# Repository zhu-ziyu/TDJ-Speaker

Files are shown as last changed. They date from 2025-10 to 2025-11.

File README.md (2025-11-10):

# Bluetooth Speaker — Design & Build Report

**Course:** TDJ4M1  
**Teacher:** Mr. Watson  
**Students:** Oscar Chen, Sam Zhu  
**Date:** Oct 1, 2025

---

## Table of Contents

- [Overview](#overview)
- [Goals & Constraints](#goals--constraints)
- [Design Criteria](#design-criteria)
- [Investigation & Research](#investigation--research)
- [Concepts & Sketches](#concepts--sketches)
- [CAD, Printing & Assembly](#cad-printing--assembly)
- [Electronics](#electronics)
- [Manufacturing Notes](#manufacturing-notes)
- [Cost & Production](#cost--production)
- [Timeline](#timeline)
- [Evaluation](#evaluation)
- [Critical Reflection](#critical-reflection)
- [Repository Structure](#repository-structure)
- [Build & Print Instructions](#build--print-instructions)
- [Future Work](#future-work)
- [License](#license)

---

## Overview

This project delivers a **compact, portable Bluetooth sound system** designed and fabricated in **Fusion 360** and produced via **3D printing**.  
The enclosure houses:

- 2 main speakers + 2 auxiliary speakers + 1 subwoofer  
- 2 control boards  
- Accessible ports, buttons, and battery compartment  
- **Magnetic fluid (“ferrofluid”) display** that “dances” to music via a controllable electromagnet  
- **Flip-top back** and **magnetic front/back coupling** for easy maintenance  
- Internal **LED illumination** that reveals **thinned light channels** in the surface design  

> The design balances **functionality, safety, and aesthetics**, ensuring stable internal structure and a futuristic, creature-like appearance.

---

## Goals & Constraints

- **Functionality:** Secure internal components, accessible ports, vibration-resistant.  
- **Printability:** Modular, fits standard FDM printers.  
- **Serviceability:** Flip-top lid, magnetic connection.  
- **Aesthetics:** Light-transmitting surface patterns, mascot features.  
- **Safety:** Rounded edges, locally compatible electronics.

---

## Design Criteria

| Category  | Specification |
|---|---|
| **Size** | Must fit within printer build volume; stable on table |
| **Function** | All buttons, speakers, and ports functional; components secured |
| **Materials** | 3D-printed plastic, strong but safe edges |
| **Aesthetics** | Clean, futuristic look with LED patterns |

---

## Investigation & Research

- **Pros:** Stable base designs, portability, good sound projection.  
- **Cons:** Spherical forms are unstable, some lack volume control.  

Key learnings:
- Front controls improve usability.  
- Symmetrical shapes enhance sound balance.  
- Transparent/lighted elements improve aesthetics.

---

## Concepts & Sketches

### Oscar’s Concept
- Cat-face front with ferrofluid as “face”  
- Multi-feet for stability and personality  
- 5-speaker array for richer audio  
- Magnetic front/back and flip-top design  
- Thinned wall patterns illuminated by LEDs  

### Sam’s Concept
- Stable internal structures for all components  
- Button extension mechanisms  
- Custom holders for speakers without screw holes  

Both ideas were combined into the final design: a cute yet futuristic speaker with advanced lighting and ferrofluid display.

---

## CAD, Printing & Assembly

> All files are available at:  
> [GitHub Repository](https://github.com/zhu-ziyu/TDJ-Speaker)

### Key Dates
- **Oct 18–19:** Initial CAD of enclosure; first test prints.  
- **Oct 20–23:** Flip-top, magnet connections, and button extensions.  
- **Oct 24:** Refined back panel and circuit board holes.  
- **Oct 27–29:** Added LED patterns and mascot; replaced electromagnet with local-safe version.  
- **Oct 31–Nov 4:** Final printing, soldering, and full assembly.

---

## Electronics

- **Main Components:** Two circuit boards, electromagnet, five speakers, LED lights.  
- **Feature:** Ferrofluid bottle reacts to music via controlled electromagnet.  
- **Fix:** Replaced unsafe imported electromagnet with Canada-compatible version.

---

## Manufacturing Notes

- **Material:** ABS (or PETG as alternative)  
- **Tolerances:** Precision snap-fits, magnet seats  
- **Orientation:** Printed to reduce visible supports  
- **Serviceability:** Flip-top hinge and magnetic coupling tested

---

## Cost & Production

| Item | Value |
|---|---|
| **Material Cost (per unit)** | $62 CAD (tax included) |
| **Print Time** | 11 hours |
| **Suggested Retail** | $128 CAD |

---

## Timeline

| Date | Activity |
|---|---|
| Oct 1–10 | Approval, drafts, PCB modeling |
| Oct 16–23 | Final draft selection, modeling, magnet design |
| Oct 24–31 | LED patterning, new electromagnet, mascot |
| Nov 3–4 | Final assembly, soldering, testing |

---

## Evaluation

### Oscar
- **Strengths:** Advanced modeling, ferrofluid feature, and LED design.  
- **Successes:** Perfect component fitting, magnet system, user-friendly assembly.  
- **Improvements:** Add programmable RGB LEDs.  
- **Learned:** Check voltage compatibility before sourcing components.

### Sam
- **Strengths:** Assembly precision, soldering, stable mounts, troubleshooting.  
- **Successes:** Solved unstable speaker issue with custom holder.  
- **Improvements:** Explore stronger, more aesthetic materials.  
- **Learned:** Early verification of parts saves time.

---

## Critical Reflection

### Oscar
- **What went well:** Implemented complex modeling and safe electronics.  
- **What to improve:** Add RGB LED system reactive to music.  
- **Learned:** Importance of regional voltage verification.  
- **If starting over:** Prototype LED and verify all components early.

### Sam
- **What went well:** Produced stable, functioning assembly.  
- **What to improve:** Research material upgrades.  
- **Learned:** Value of creating testing protocols early.  
- **If starting over:** More testing time for final soldering.

---

## Repository Structure

.
├── README.md
├── cad/
│ ├── fusion360/
│ └── assemblies/
├── stl/
│ ├── front_panel/
│ ├── back_panel_flip_top/
│ ├── magnet_couplers/
│ ├── button_extensions/
│ ├── speaker_holders/
│ └── feet_and_decors/
├── electronics/
│ ├── schematic/
│ └── bom.csv
├── docs/
│ ├── images/
│ ├── daily-tracker.md
│ └── evaluation.md
└── licenses/
└── LICENSE

---

## Build & Print Instructions

1. **Print**
   - Material: ABS/PETG  
   - Layer height: 0.2 mm  
   - Infill: 25%  
   - 3–4 perimeters  
   - Iron top surfaces if needed  

2. **Assemble**
   - Press magnets into couplers  
   - Mount speakers, electromagnet, ferrofluid bottle  
   - Connect wiring and solder  
   - Attach LEDs and test illumination  
   - Assemble front/back using magnetic connection  

3. **Test**
   - Audio balance  
   - Button functionality  
   - LED brightness and uniformity  

---

## Future Work

- RGB addressable LEDs  
- Stronger materials (carbon-fiber-filled filament)  
- Better acoustic dampening  
- Improved electromagnet power efficiency  
- Instruction manual and print guide

---

## License

Licensed under MIT License.  
© 2025 Oscar Chen & Sam Zhu — *Making sound you can see.* 🎧

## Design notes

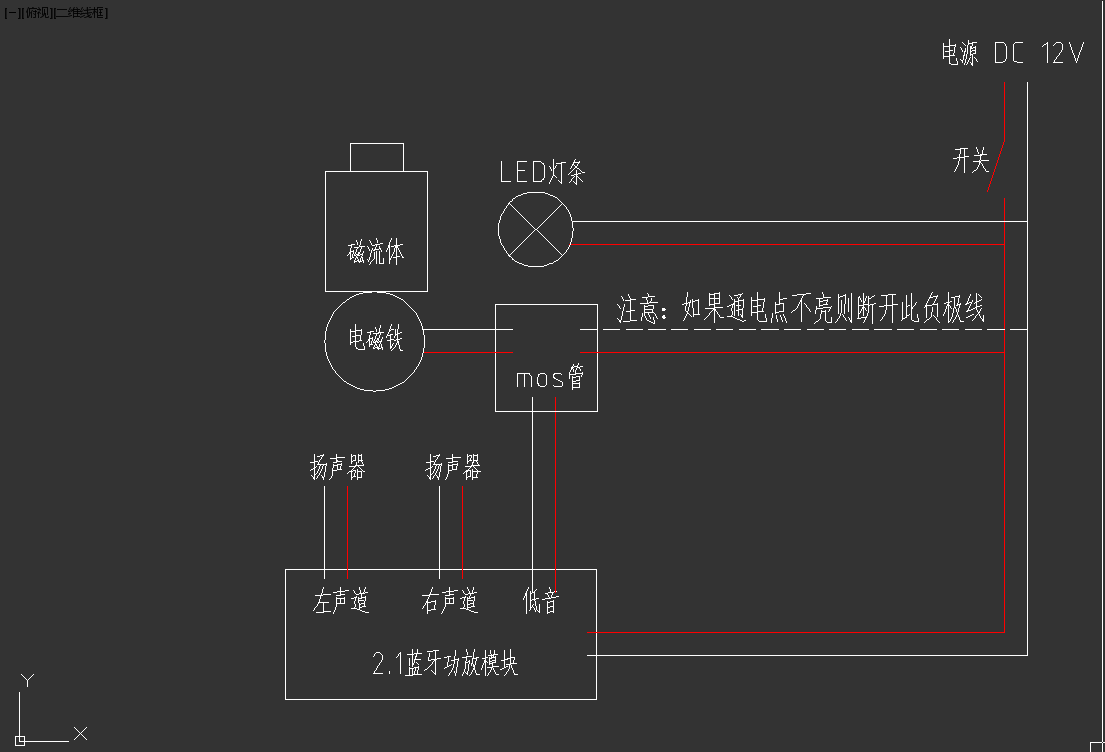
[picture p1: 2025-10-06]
参考文献/电路连接(来自毕导TSU的立创开源).png

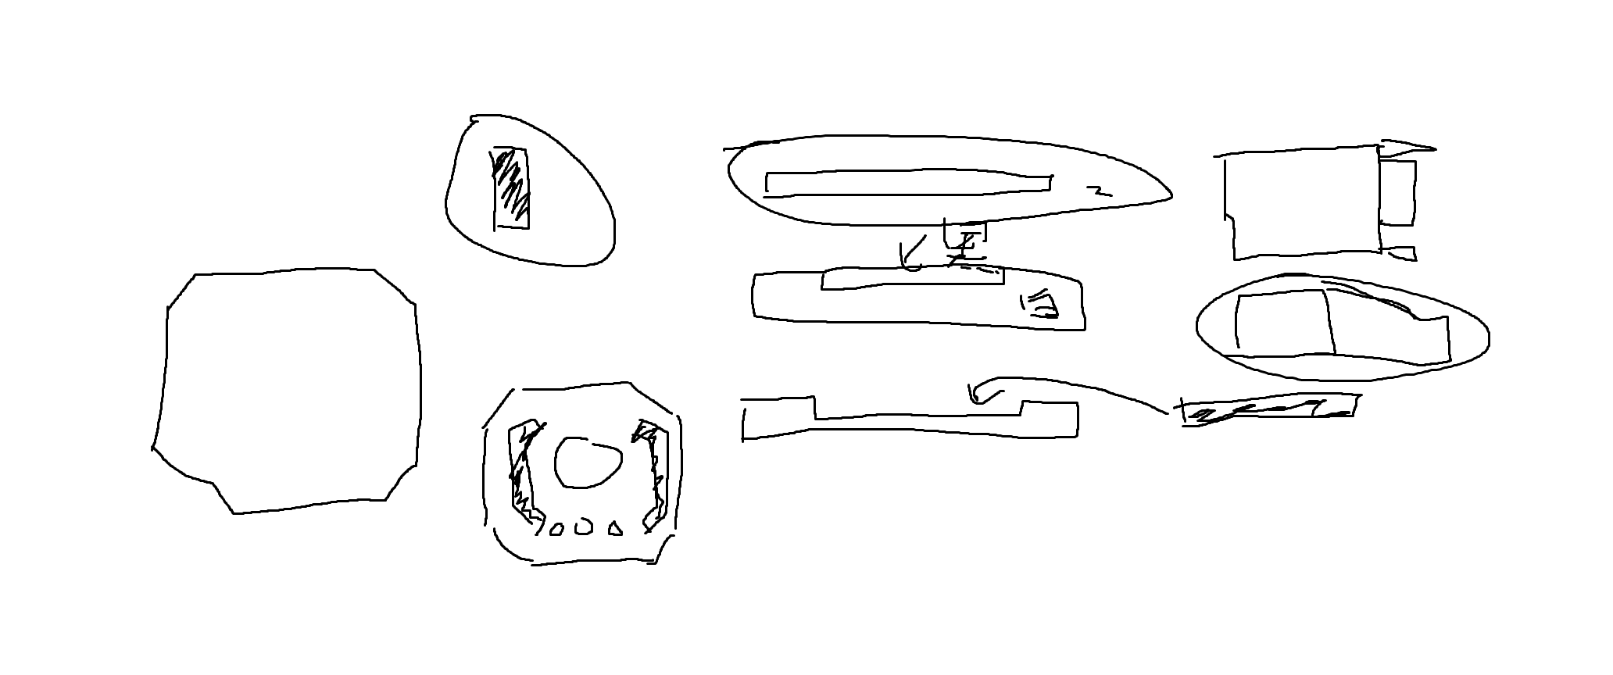
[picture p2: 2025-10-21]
参考文献/无标题.png

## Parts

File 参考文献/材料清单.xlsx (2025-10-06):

材料 | 规格 | 数量 | 参考链接 | 备注
磁流体 | 5ML | 1 | https://item.taobao.com/item.htm?spm=a1z09.2.0.0.559e2e8dW8ySWr&id=677427611678&_u=qd0tp5fba4c
蓝牙音频功放 | XY-E30H | 1 | https://item.taobao.com/item.htm?spm=a1z09.2.0.0.559e2e8dW8ySWr&id=659648902441&_u=qd0tp5fea37
MOS场效应管 |  | 1 | https://item.taobao.com/item.htm?spm=a1z09.2.0.0.559e2e8dW8ySWr&id=664398882601&_u=qd0tp5f3cde
喇叭 | 5W 4欧 52mm方形 2英寸 红色 | 2 | https://item.taobao.com/item.htm?spm=a1z09.2.0.0.559e2e8dW8ySWr&id=543234965961&_u=qd0tp5fefb4
电磁铁 | 黄色[KK-P25/25通孔M6]电压DC12V | 1 | https://item.taobao.com/item.htm?spm=a1z09.2.0.0.559e2e8dW8ySWr&id=521131277777&_u=qd0tp5f2c70
led灯 | 12v5mm宽-白6500K-0.5米 | 1 | https://item.taobao.com/item.htm?spm=a1z09.2.0.0.559e2e8dW8ySWr&id=638973103783&_u=qd0tp5f45c7
电源开关 | 电压：12-24V功能：自锁式【按下锁住】安装尺寸：16mm | 1 | https://item.taobao.com/item.htm?spm=a1z09.2.0.0.559e2e8dW8ySWr&id=560789879755&_u=qd0tp5f24f8
LED开关 | 1 | 1 | https://item.taobao.com/item.htm?spm=a1z10.3-c-s.w4002-14479784363.22.1a58643btDS6fy&id=641296688833
电源开关 | 白色12V2A适配器 DC5.5-2.1 | 1 | https://item.taobao.com/item.htm?spm=a1z09.2.0.0.6f752e8dmY1v3K&id=676647796601&_u=qd0tp5fc01e
电源母座插口 | (5个)DC022B插座 5.5*2.1 全铜质 | 1 | https://item.taobao.com/item.htm?spm=a1z09.2.0.0.6f752e8dmY1v3K&id=4247489135&_u=qd0tp5f7924
螺丝 | m3*10 | 10 | https://detail.tmall.com/item.htm?id=634410753197&spm=a1z09.2.0.0.6f752e8dmY1v3K&_u=qd0tp5fae2f
螺丝（配螺母） | M4*10 | 10 | https://detail.tmall.com/item.htm?id=634410753197&spm=a1z09.2.0.0.6f752e8dmY1v3K&_u=qd0tp5fae2f
其他 | 热熔胶，电线，电烙铁等电子制做常用工具

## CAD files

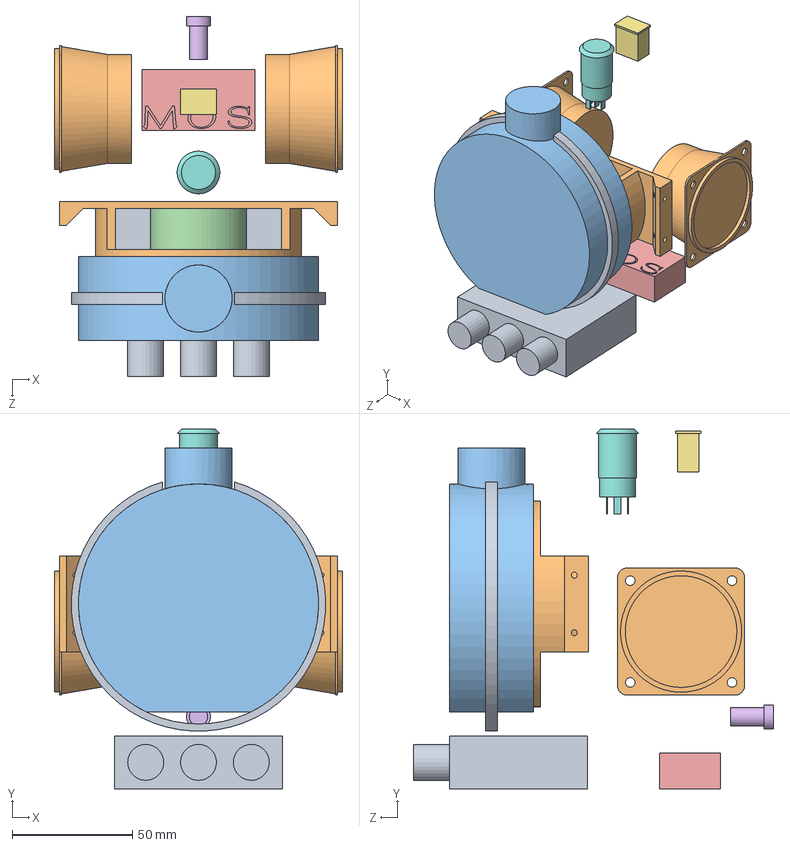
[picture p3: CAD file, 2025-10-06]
参考文献/磁流体音响/音响装配.SLDASM
120.0 x 149.8 x 150.0 mm
功放
喇叭 x 2
瓶子
电磁铁
mos
充电口
船开
自锁开关16mm
音响led
电磁铁固定

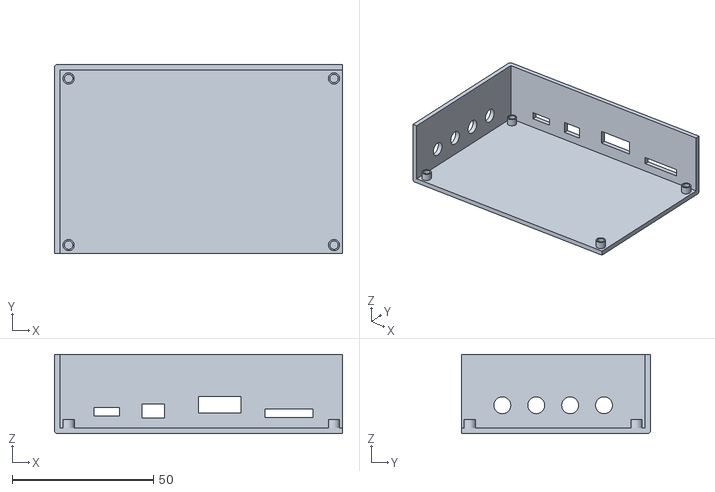
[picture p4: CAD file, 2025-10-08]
holder final version stl.stl
102.0 x 67.0 x 28.0

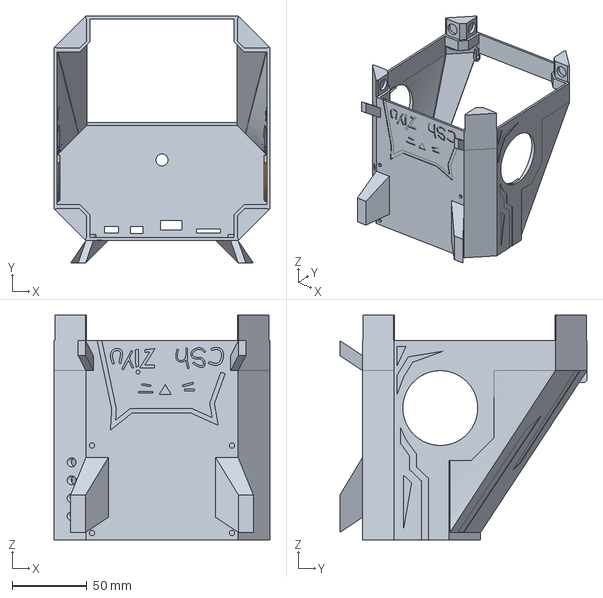
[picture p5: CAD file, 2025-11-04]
waike/waikehoubuv6.step
144.0 x 165.0 x 150.0 mm

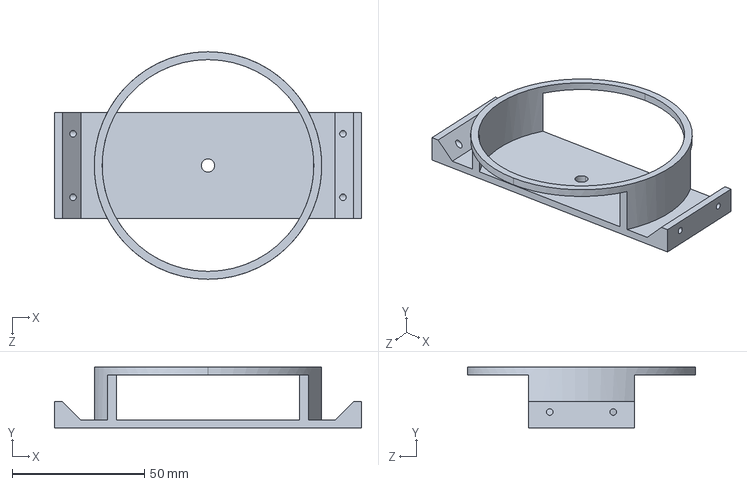
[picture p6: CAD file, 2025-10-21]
参考文献/电磁铁固定.STEP
116.0 x 23.0 x 86.0 mm

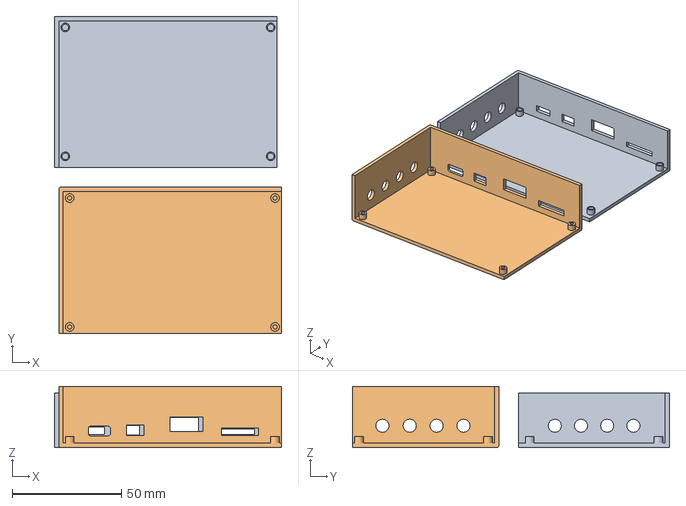
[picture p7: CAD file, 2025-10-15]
参考文献/磁流体音响/Untitled.3mf
104.0 x 145.1 x 28.0 mm
Untitled.obj
Oscar Chen holder final version.stl

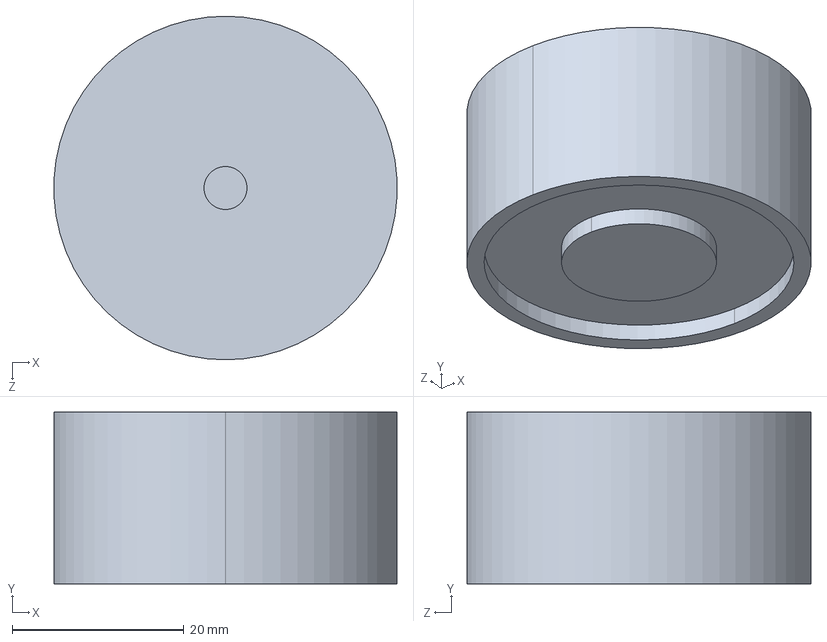
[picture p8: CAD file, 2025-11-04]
杂/电磁铁.STEP
39.9 x 20.0 x 40.0 mm

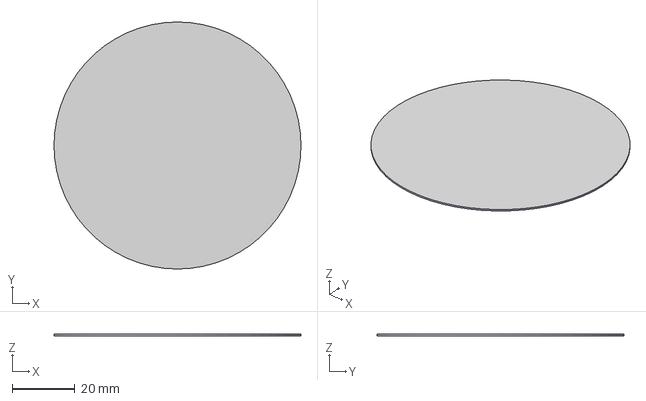
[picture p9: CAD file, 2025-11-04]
other/Untitled11111.step
79.0 x 79.0 x 0.5 mm

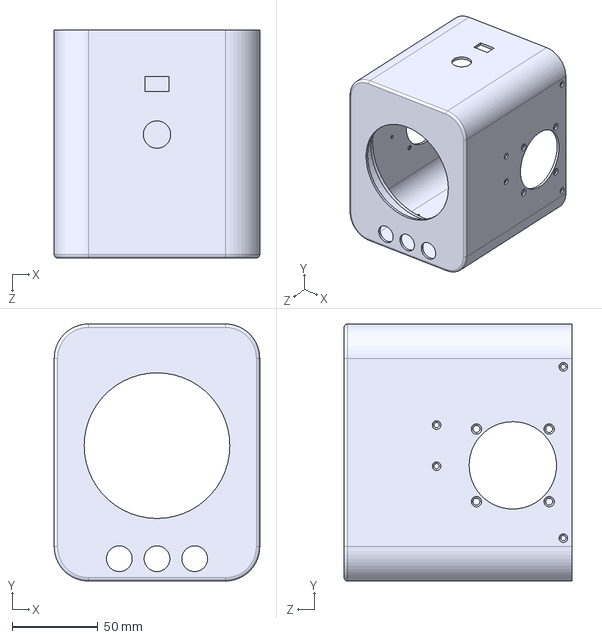
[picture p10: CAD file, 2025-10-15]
参考文献/外壳A.STEP
120.0 x 150.0 x 133.0 mm

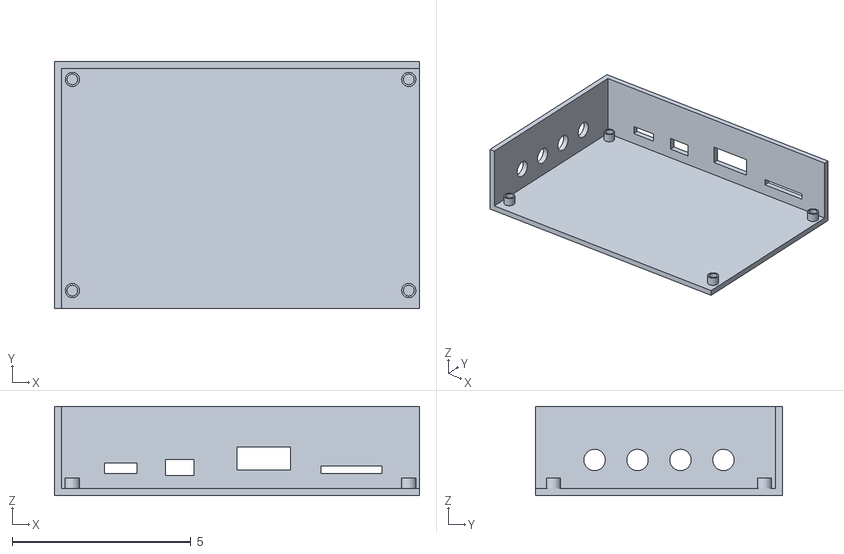
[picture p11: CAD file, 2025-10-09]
参考文献/磁流体音响/v2kezi.obj
10.2 x 6.90 x 2.50

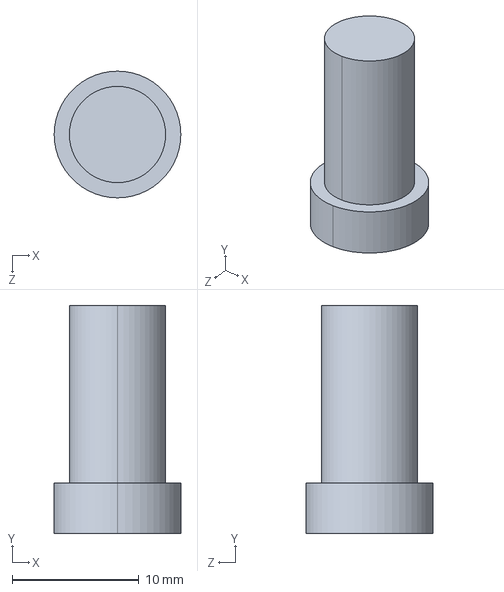
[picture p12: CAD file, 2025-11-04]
杂/充电口.STEP
10.0 x 18.0 x 10.0 mm

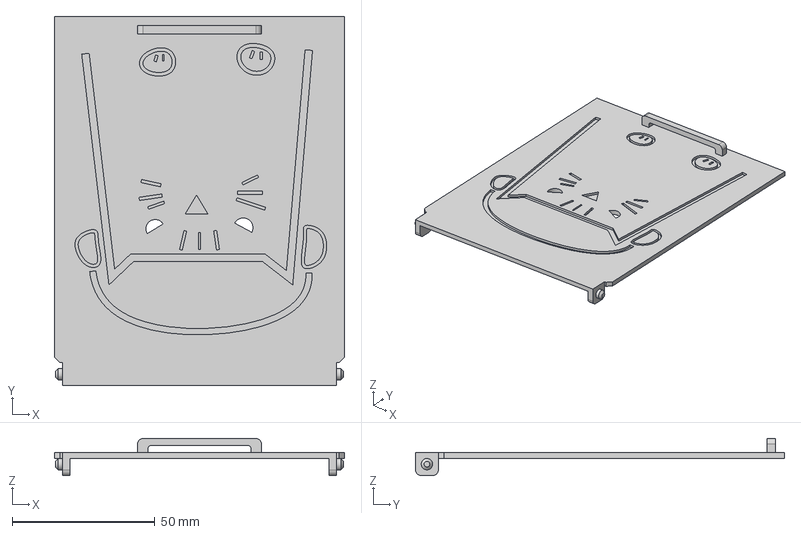
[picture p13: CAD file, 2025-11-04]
other/盖子.step
101.7 x 129.2 x 13.0 mm

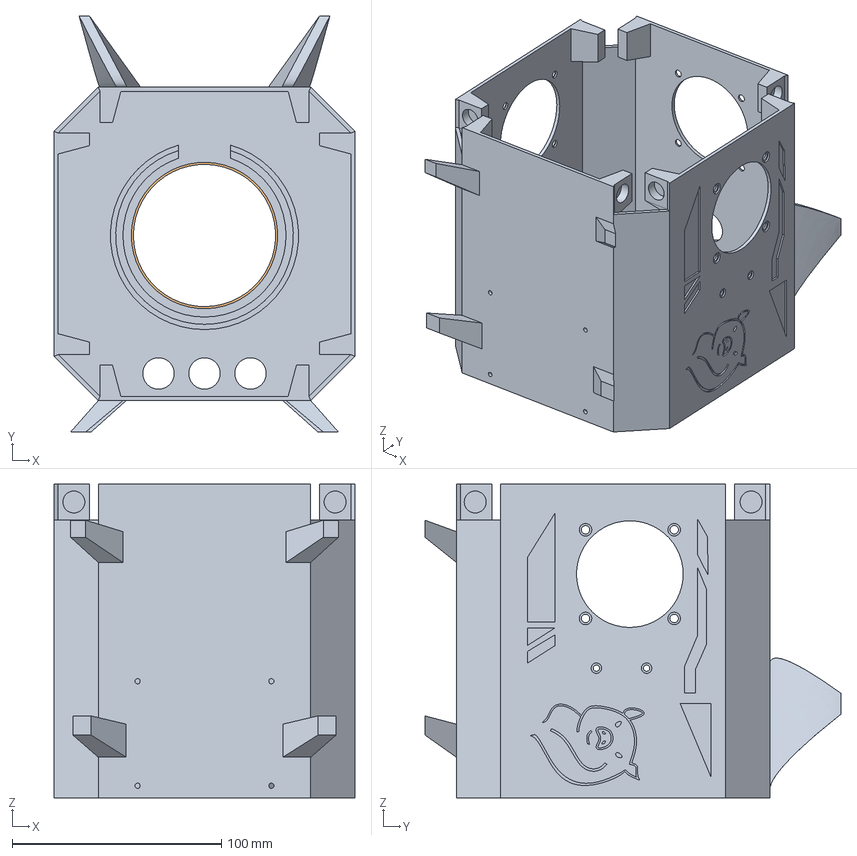
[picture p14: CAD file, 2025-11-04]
waike/Techdesign Speaker 3d designv8.step
144.0 x 199.0 x 150.0 mm

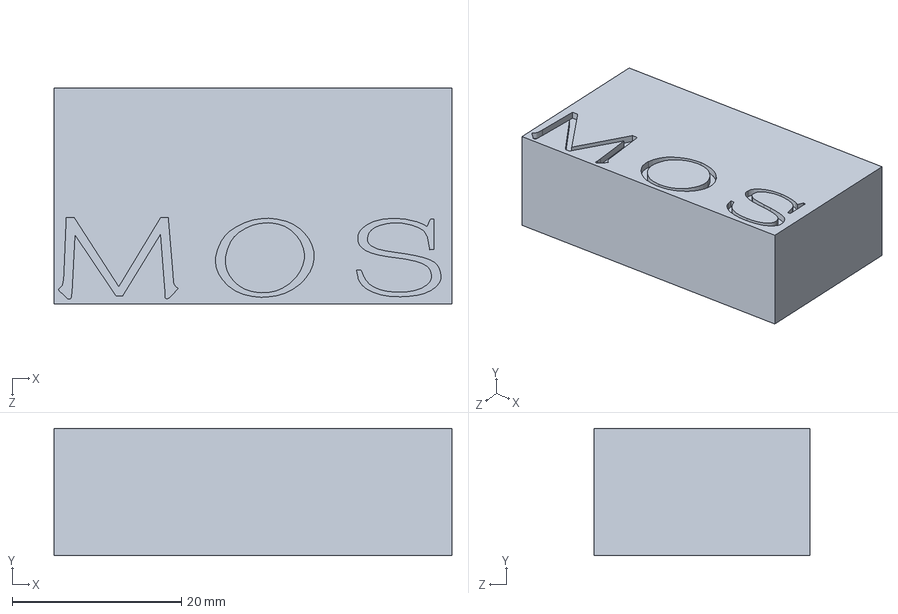
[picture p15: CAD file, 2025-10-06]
参考文献/磁流体音响/mos.SLDPRT
47.0 x 15.0 x 25.5 mm

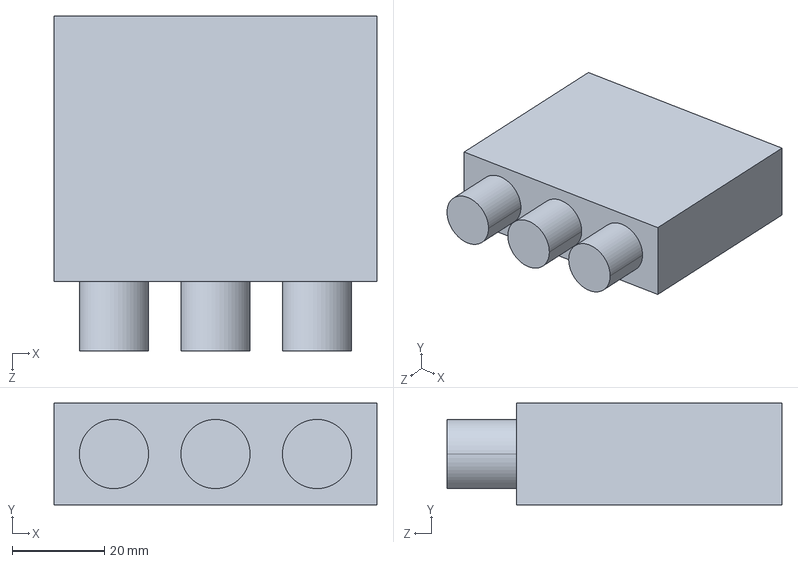
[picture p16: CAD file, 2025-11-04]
杂/功放.STEP
70.0 x 22.0 x 72.5 mm

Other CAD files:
Holder/Oscar Chen Holder 10.15 版本2.stl
Holder/Oscar Chen Holder 10.15 版本1.stl
Holder/Untitled.obj
Holder/Oscar Chen holder final version.stl
Assembly.f3z
XHA150hezi.f3d
other/diancitie.step
other/diancitiev1.step
other/diancitiev2.f3d
other/diancitiev2.step
other/diancitiev3.step
other/diancitiev4.f3d
other/diancitiev5.f3d
other/diancitiev5.step
other/diancitiev6.step
other/diancitiev7.step
other/大磁铁.f3d
other/小磁铁.f3d
other/盖子v1.step
other/盖子v2.step
other/老师给的音响.f3d
other/老师给的音响.step
waike/Techdesign Speaker 3d design.f3d
waike/Techdesign Speaker 3d designv4.3mf
waike/Techdesign Speaker 3d designv4.f3d
waike/Techdesign Speaker 3d designv4.step
waike/Techdesign Speaker 3d designv5.step
waike/Techdesign Speaker 3d designv6.step
waike/Techdesign Speaker 3d designv8.f3d
waike/backv1.3mf
waike/backv1.step
waike/v2.obj
waike/v2.step
waike/waikebhoubuv1.f3d
waike/waikehoubu.f3d
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

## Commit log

2025-10-07 1
    1
    [XAH-105.f3d]
2025-10-08 holder
    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
    [holder final version stl.stl, kezi.f3d]
2025-10-15 11
    11
    [酒瓶子.f3d]
2025-10-22 update 盖子.f3d
    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
    [盖子.f3d]
2025-10-23 update for 按钮头 and 盖子
    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
    [按钮头.f3d, 盖子.f3d]
2025-11-10 Revise README for Bluetooth Speaker project report
    Updated the README to provide a comprehensive design and build report for the Bluetooth speaker project, including sections on goals, design criteria, research, assembly, and evaluation.
